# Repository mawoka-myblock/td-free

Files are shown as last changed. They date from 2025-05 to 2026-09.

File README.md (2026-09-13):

# Td-Free

A free and open source device to measure the td value of your filaments.

The CAD is available in the [onshape workspace](https://cad.onshape.com/documents/e7ec65aec40b24c9a33c1902/w/dc90f86d4d08d2181a707cee/e/a86c6c8c0a4124509901ffce)
(licensed under [CC BY-SA 4.0](https://creativecommons.org/licenses/by-sa/4.0/)) and the print files can be downloaded from [Printables](https://www.printables.com/model/919380-td-free)

## Comparison to TD-1 by Ajax

| TD-Free | TD-1 |
| --- | --- |
| **Small** | Slightly bigger |
| **Cheap** | More expensive |
| Measures td and color | **Measures color and td** |
| WiFi-enabled | Only via usb and screen |
| **Open-Source Code** | Closed source |
| **No license required** | License needs to be purchased |
| No integrations available | **Perfectly integrated into HueForge** |
| **CAD available** | CAD not available |
| only for checking samples | **monitor td of spool as it's printing** |

So, in summary, the Td-Free is **cheaper**, **open-source**, **smaller** and **wifi-enabled**.

## Buy one

**Explore [my online store](https://mawoka.eu/shop) where you can buy the PCB or a fully assembled Td-Free.**

## Make one

### Buy only the PCB

If you got the PCB, just print the parts provided at [Printables](https://www.printables.com/model/919380-td-free-an-open-source-alternative-to-the-td-1).
You have to use black filament for the specifc parts marked as such, but for the others, you can mix and match them! Let's get to the assembly:

1. Insert the LED module into the position in the case at the bottom. Press it down firmly.
2. Insert the two black pieces. The one with the channel first, so that the channel is open to the top. Make sure you see the yellow LED module through the hole in the channel!
3. Now, insert the second black piece with the rectangular cutout as well. Make sure again that the cutout is above the LED hole.
4. Slide the PCb with the USB-C connector in at an angle and make sure it's fully slid in.
5. Push the PCb into place and make sure it is really sitting flat. **Watch out for the LED cable to not get damaged!**
6. Put the lid on
7. Done! Measure your Td!

### From Scratch
Get the PCB from a manufacturer like JLCPCB, PCBway or whatever. Now, you'll also want to get the following components:
- `VEML7700` (TR or TT is only about the packaging, so choose the cheaper one)
- `WS2812B` (In the 5050 variant)
- `ESP32-C3 Supermini` ([Here from AliExpress](https://s.click.aliexpress.com/e/_DmNdnTB))
- `AOSS32334C`
- [This LED module](https://s.click.aliexpress.com/e/_DF3Gdpb) Get the Cold White version

Solder all your parts to the PCB. The LED module cables have to solderd from the bottom and should be around 45mm long.
Now, follow all the steps from above. For flashing, just follow the instructions to get Esp-rs working and run `cargo run --release`.

## Looking for the old README?
Click [here](https://github.com/mawoka-myblock/td-free/blob/v2.0.0/README.md).

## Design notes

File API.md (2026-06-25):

# API Docs

## REST

### GET / App HTML
Gets the main index.html

### GET /app.js App JS
Gets the main app.js

### GET /app.css App CSS
Gets the main app.css

### GET /events/data SSE for data
Gets the data measured by the device.

Event is `measurement_changed` and either contains:

```
no_filament
```

or

```json
{
    "td": "2.5",
    "hex_color": Option<"FFFFFF">,
    "buf_color": Option<12>
}
```

### GET/POST /config/settings Set/Get Config
Sets/Gets settings:

```json5
{
    "led_brightness": 100, // in %
    "algo": {
        "b": 0.0,
        "m": 1.0,
        "threshold": 0.9 // between 0.999 and 0.001
    }
}
```

### GET/POST /config/rgb Set/Get RGB Multipliers
Sets/Gets rgb multipliers:
```json
{
    "red": 1.0,
    "green": 1.0,
    "blue": 1.0,
    "brightness": 1.0,
    "td_reference": 50.0,
    "reference_r": 127,
    "reference_g": 127,
    "reference_b": 127
}
```

### POST /config/wifi Set Wifi Credentials
```json
{
    "ssid": "dsada",
    "password": "dsads"
}
```

### GET /config/info Get Device Info
```json
{
    "has_color": true,
    "version": "06556+4-3.3"
}
```

### POST /config/auto-calibrate Set Auto-calibrate data
Need client listening to server sent events (`/events/data`)

may throw 428 if no client connected

may throw 408 if internal function timeouted

```json
{
    "target_r": 255,
    "target_g": 255,
    "target_b": 255
}
```

Return RGBMultipliers like `/config/rgb`

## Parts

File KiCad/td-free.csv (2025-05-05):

Id | Designator | Footprint | Quantity | Designation | Supplier and ref
1 | U1 | ESP32-C3-WROOM-02 | 1 | ESP32-C3-WROOM-02
2 | J1 | PinHeader_1x02_P2.54mm_Vertical | 1 | Conn_01x02_Pin
3 | U4 | SMD_L3328_VIS | 1 | VEML3328
4 | J2 | USB_C_Receptacle_GCT_USB4105-xx-A_16P_TopMnt_Horizontal | 1 | USB_C_Receptacle_USB2.0_14P
5 | U5 | USON-10_2.5x1.0mm_P0.5mm | 1 | TPD4E05U06DQA
6 | U3 | SOT-223-3_TabPin2 | 1 | AMS1117-3.3
7 | U2 | XDCR_VEML7700-TR | 1 | VEML7700-TT
8 | R3 | R_0805_2012Metric_Pad1.20x1.40mm_HandSolder | 1 | 10kO
9 | R2,R1 | R_0805_2012Metric_Pad1.20x1.40mm_HandSolder | 2 | 5k1
10 | D2 | D_SMA | 1 | SMAJ5.0A
11 | C6,C4,C1 | C_0805_2012Metric_Pad1.18x1.45mm_HandSolder | 3 | 10uF
12 | C5 | C_0805_2012Metric_Pad1.18x1.45mm_HandSolder | 1 | 0.1uF
13 | C3,C2 | C_0805_2012Metric_Pad1.18x1.45mm_HandSolder | 2 | 22uF
14 | D1 | LED_WS2812B_PLCC4_5.0x5.0mm_P3.2mm | 1 | WS2812B
15 | Q1 | SOT-23 | 1 | 2N7002

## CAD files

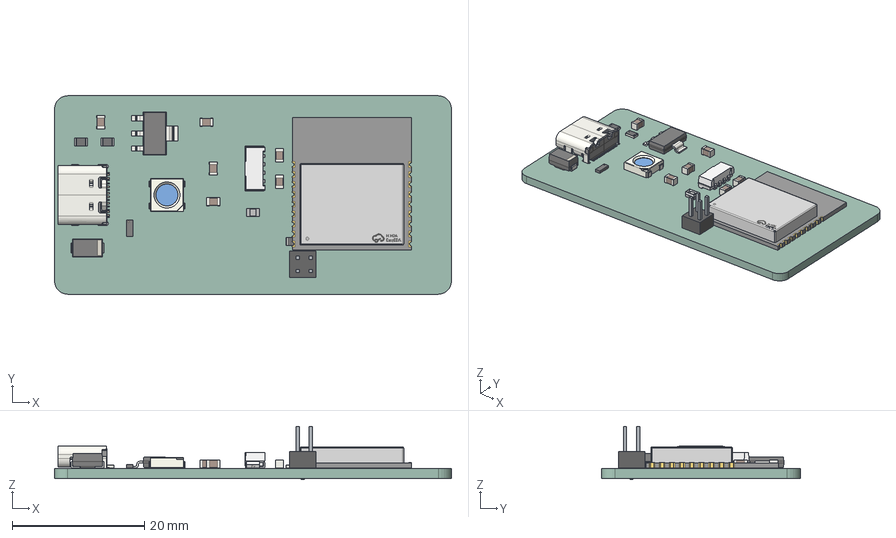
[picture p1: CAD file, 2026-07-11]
KiCad/boards/main.step
60.0 x 30.0 x 8.05 mm
USB_C_Receptacle_16P_TopMnt_Horizontal_GCT_USB4105-xx-A
BULETM-SMD_ESPRESSIF_ESP32-C3-WROOM-02-N4-4MB
R_0805_2012Metric x 3
LED-SMD_4P-L6.8-W2.4_VEML7700-TR
C_0805_2012Metric x 6
USON_10_25x10mm_Pitch05mm
SENSOR-SMD_VEML3328
LED_WS2812B_PLCC4_50x50mm_P32mm
SOT-223
2x2 Header
D_SMA
main_PCB

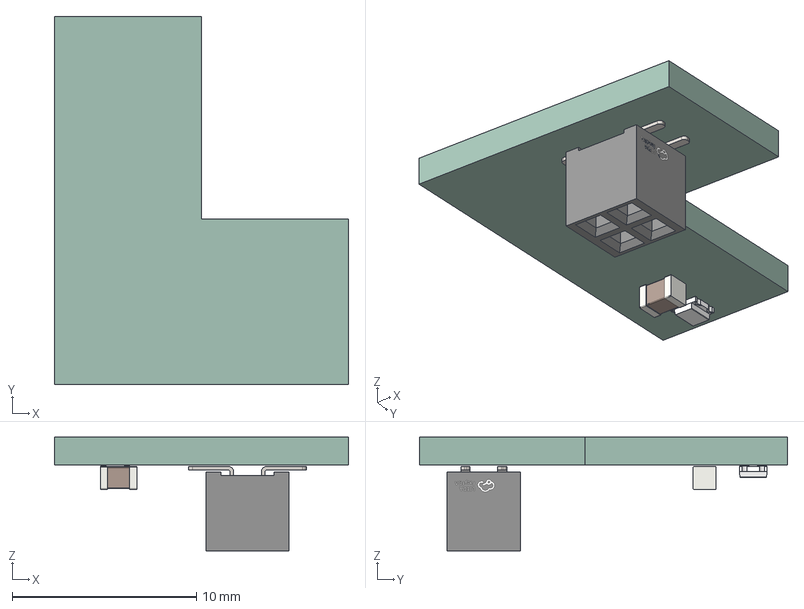
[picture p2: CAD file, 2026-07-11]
KiCad/boards/led.step
16.0 x 20.0 x 6.19 mm
LED-SMD_4P-L1.6-W1.5_XL-1615RGBC-WS2812B-1
C_0805_2012Metric
HDR-SMD_4P-P2.00-V-F-R2-C2-LS6.4
led_PCB

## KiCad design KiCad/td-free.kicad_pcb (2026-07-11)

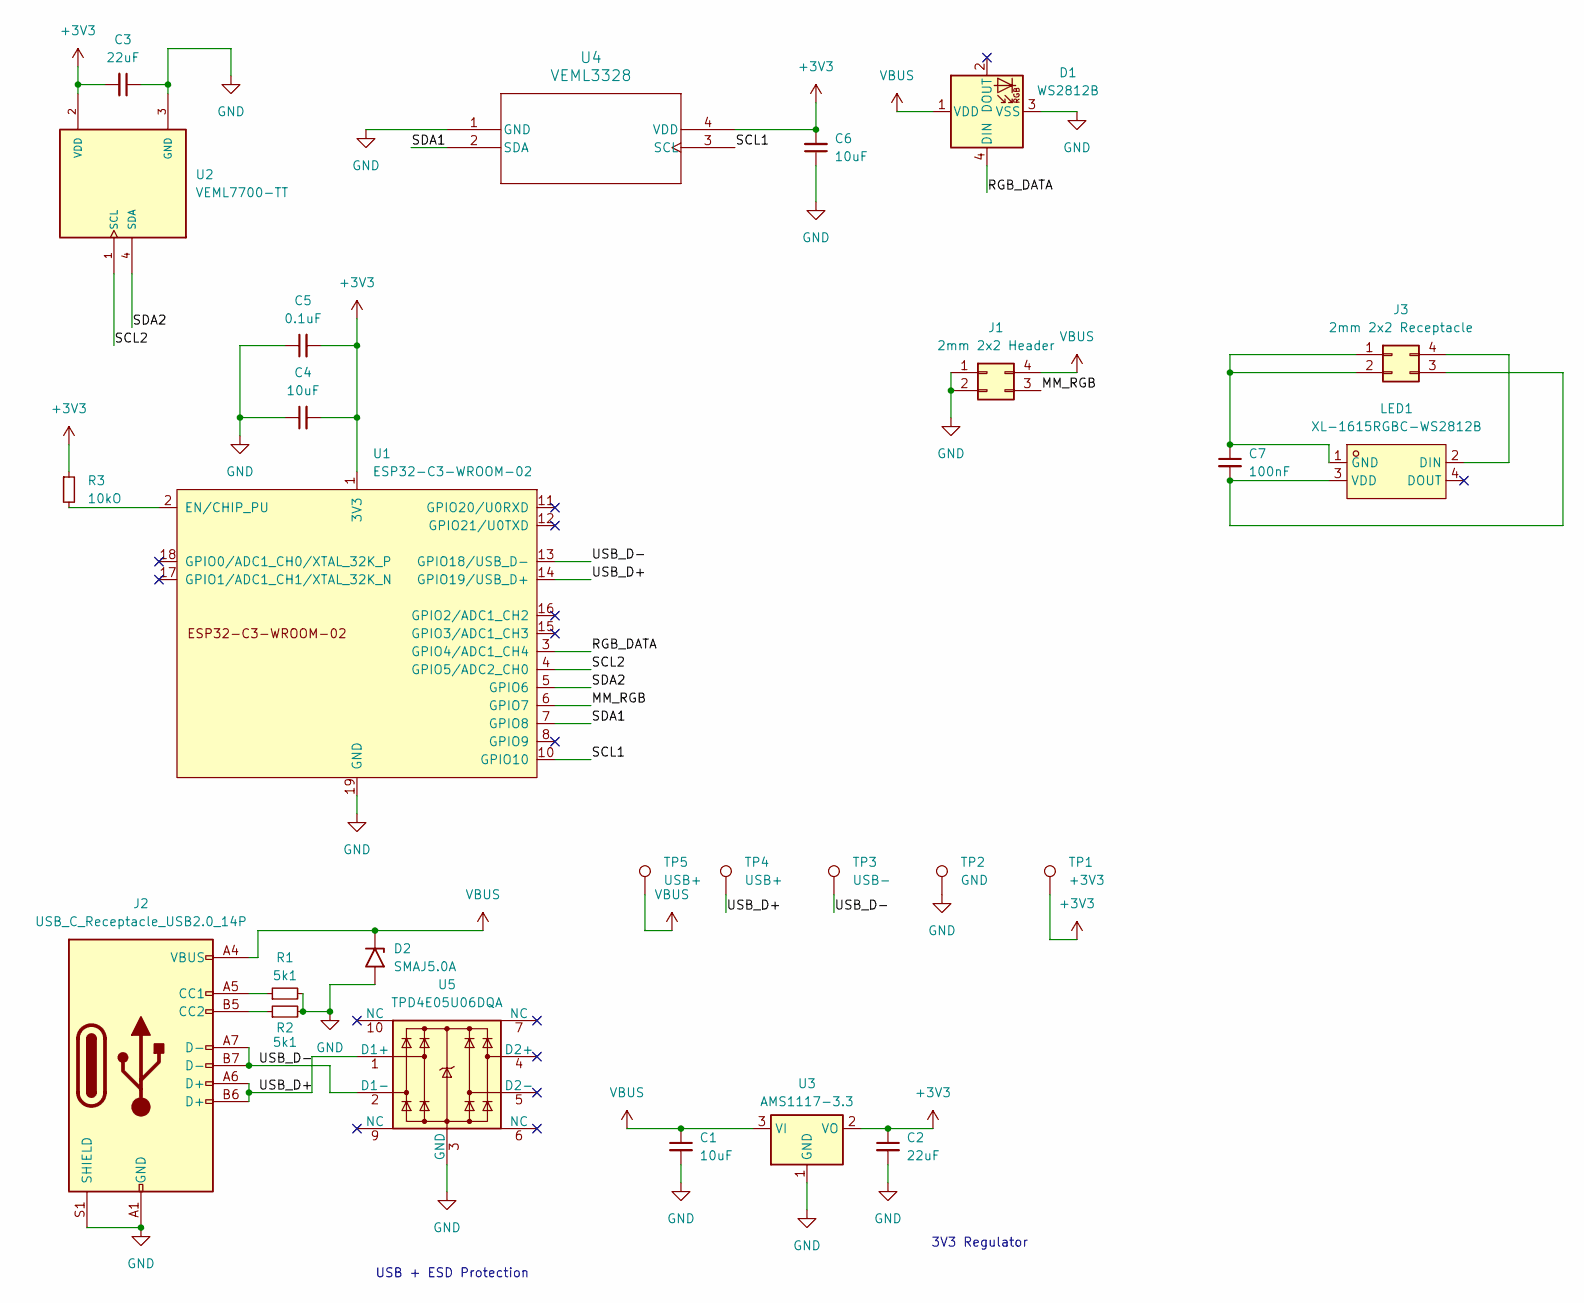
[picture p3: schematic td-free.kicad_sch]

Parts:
C1, C4, C6: 10uF; C_0805_2012Metric
C2, C3: 22uF; C_0805_2012Metric
C5: 0.1uF; C_0805_2012Metric
C7: 100nF; C_0805_2012Metric
D1: WS2812B; LED_WS2812B_PLCC4_5.0x5.0mm_P3.2mm
D2: SMAJ5.0A; D_SMA
J1: 2mm 2x2 Header; HDR-SMD_4P-P2.00-V-M-R2-C2-LS6.4-EH
J2: USB_C_Receptacle_USB2.0_14P; USB_C_Receptacle_GCT_USB4105-xx-A_16P_TopMnt_Horizontal
J3: 2mm 2x2 Receptacle; PinHeader_2x02_P2.00mm_Vertical_SMD
LED1: XL-1615RGBC-WS2812B; LED-SMD_4P-L1.6-W1.5_XL-1615RGBC-WS2812B-1; LCSC Part C5349954
R1, R2: 5k1; R_0805_2012Metric_Pad1.20x1.40mm_HandSolder
R3: 10kO; R_0805_2012Metric_Pad1.20x1.40mm_HandSolder
TP1: +3V3; TestPoint_Pad_D1.0mm
TP2: GND; TestPoint_Pad_D1.0mm
TP3: USB-; TestPoint_Pad_D1.0mm
TP4, TP5: USB+; TestPoint_Pad_D1.0mm
U1: ESP32-C3-WROOM-02
U2: VEML7700-TT; XDCR_VEML7700-TT; PARTREV 1.6
U3: AMS1117-3.3; SOT-223-3_TabPin2
U4: VEML3328; SMD_L3328_VIS
U5: TPD4E05U06DQA; USON-10_2.5x1.0mm_P0.5mm

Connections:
+3V3: C2.1, C3.2, C4.2, C5.2, C6.2, R3.1, TP1.1 (1_1), U1.1 (3V3), U2.2 (VDD), U3.2 (VO), U4.4 (VDD)
/MM_RGB: J1.3, U1.6 (GPIO7)
/RGB_DATA: D1.4 (DIN), U1.3 (GPIO4/ADC1_CH4)
/SCL1: U1.10 (GPIO10), U4.3 (SCL)
/SCL2: U1.4 (GPIO5/ADC2_CH0), U2.1 (SCL)
/SDA1: U1.7 (GPIO8), U4.2 (SDA)
/SDA2: U1.5 (GPIO6), U2.4 (SDA)
/USB_D+: J2.A6 (D+), J2.B6 (D+), TP4.1 (1_1), U1.14 (GPIO19/USB_D+), U5.1 (D1+)
/USB_D-: J2.A7 (D-), J2.B7 (D-), TP3.1 (1_1), U1.13 (GPIO18/USB_D-), U5.2 (D1-)
GND: C1.2, C2.2, C3.1, C4.1, C5.1, C6.1, D1.3 (VSS), D2.2 (A2), J1.1, J1.2, J2.A1 (GND), J2.A12 (GND), J2.B1 (GND), J2.B12 (GND), J2.S1 (SHIELD), R1.2, R2.2, TP2.1 (1_1), U1.9 (GND), U1.19 (GND), U2.3 (GND), U3.1 (GND), U4.1 (GND), U5.3 (GND), U5.8 (GND)
unnamed: J2.A5 (CC1), R1.1
unnamed: J2.B5 (CC2), R2.1
unnamed: C7.1, J3.1, J3.2, LED1.1 (GND)
unnamed: C7.2, J3.3, LED1.3 (VDD)
unnamed: J3.4, LED1.2 (DIN)
unnamed: R3.2, U1.2 (EN/CHIP_PU)
VBUS: C1.1, D1.1 (VDD), D2.1 (A1), J1.4, J2.A4 (VBUS), J2.A9 (VBUS), J2.B4 (VBUS), J2.B9 (VBUS), TP5.1 (1_1), U3.3 (VI)

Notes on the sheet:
3V3 Regulator
USB + ESD Protection

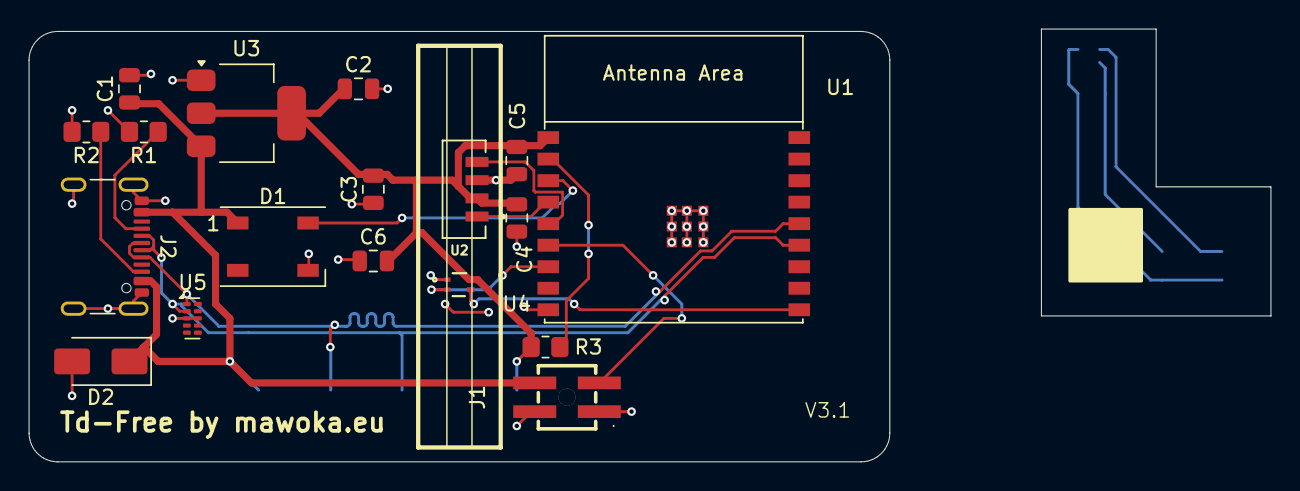
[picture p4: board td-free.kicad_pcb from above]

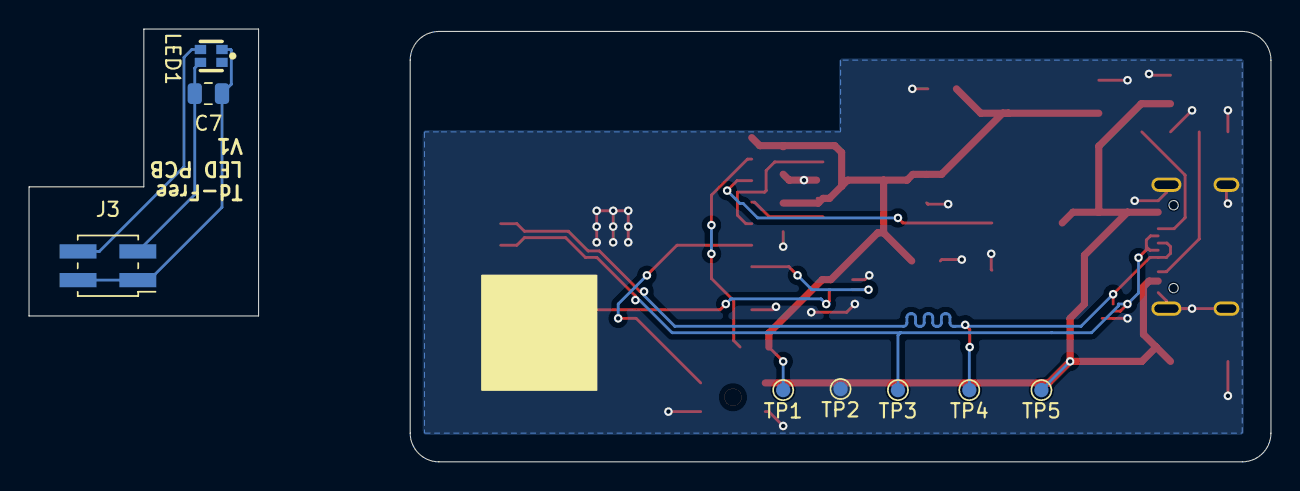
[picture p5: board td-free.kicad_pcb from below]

Board: 2 copper layers, 60.0 x 30.0 mm, 28 parts (8 on the bottom side), 17 nets.

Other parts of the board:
B1, B2: Board

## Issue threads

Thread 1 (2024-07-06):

No build available

Johannes-Sch, 2024-07-06:
Hi,
at the moment there is no build available and the link in the flashing instructions gives a 404 error.
Could you please upload a release?

Thanks and KR
Johannes

Johannes-Sch, 2024-07-06:
Thanks for the fast reply!

I used the image with this command to flash it:
.\esptool.exe -b 230400 write_flash 0x0 .\firmware.bin

But I get the following error:
Unexpected chip id in image. Expected 0 but value was 5. Is this image for a different chip model?
A fatal error occurred: .\firmware.bin is not an ESP32 image. Use --force to flash anyway.

I use the ESP32-C3 that is linked in the Shopping List.

If I use .\esptool.exe -b 230400 write_flash 0x0 .\firmware.bin --force to flash it anyway it does go through but when I power everything the red LED on the board stays on, the blue LED is blinking and there is no wifi hotspot (even after a few minutes there is no change to that).

Any idea what the problem is or how I can debug this?

mawoka-myblock, 2024-07-06:
Try erasing the chip (`esptool.exe erase_flash`) and maybe try again

mawoka-myblock, 2024-07-06:
I've missed mentioning a crucial step: Holding the `BOOT` button while plugging the esp in.

Johannes-Sch, 2024-07-06:
I tried erasing the chip and flashing it again (also with the --force argument). Before flashing, I was holding the boot button, which resulted in no blue LED flashing while flashing the image.

Sadly, there is no change in the behavior when plugin it into power. Is there a way to verify if the flashing was even successful, or is the blue LED flashing already an indication that it was not?

mawoka-myblock, 2024-07-06:
If you only erase the chip, does it then stop blinking blue? When the correct firmware is flashed, it should only blink periodically and not constantly that fast.

mawoka-myblock, 2024-07-06:
Nevermind, the chip shouldn't flash at all with the correct firmware when none of the other components are attached.

Johannes-Sch, 2024-07-06:
Okay, I made an interesting discovery. On my main PC, I always had to use the --force argument. I now tried flashing the firmware with my laptop (also with a different cable USB-C to USB-C instead of USB-A to USB-C but not sure if that makes a difference)

mawoka-myblock, 2024-07-06:
It *shouldn't* make a difference

Johannes-Sch, 2024-07-06:
I tried reading the serial output with the serial monitor in the Arduino IDE. After flashing, I get this message (it repeats this):

load:0x4038c1bc,len:0x14cc
ESP-ROM:esp32c3-api1-20210207
Build:Feb  7 2021
rst:0x7 (TG0WDT_SYS_RST),boot:0xf (SPI_FAST_FLASH_BOOT)
Saved PC:0x40380080
SPIWP:0xee
mode:DIO, clock div:1
load:0x3c0a0020,len:0x20390
load:0x3fc8d800,len:0x3a9c
load:0x40380000,len:0xc1bc
load:0x42000020,len:0x95920
load:0x4038c1bc,len:0x14cc
SHA-256 comparison failed:
Calculated: cebc1b341a418d75d08e64a66da52bdc3515c5817809a3983f2c00b1bb60a996
Expected: 0101a90055996720ee2eec6ad3d34a4aa37930cc65991d86f5ce4ffbd98c362c
Attempting to boot anyway...
entry 0x40381d74

mawoka-myblock, 2024-07-06:
Did you buy a second esp32c3? It seems like the storage (flash) on it may be broken. I'll remove this specifc vendor from the list.

Johannes-Sch, 2024-07-06:
I just ordered two new ones from a different vendor. One good thing with AliExpress: already got my money back.
I will try again in about a week when the new ones are delivered.

Johannes-Sch, 2024-07-16:
Alright, today two new esp's got delivered.
I tried flashing it again with .\esptool.exe -b 230400 write_flash 0x0 .\firmware.bin however again got the same error as last time;

Next, I downloaded the entire project from git and uploaded a newly compiled firmware directly from VSCode. This was indeed successful! The Td-Free hotspot can be seen and connected to.

Don't know if that's the problem, but in the VS project the upload_speed is set to 460800 and in the flash command the rate is set to 230400. (Probably not, just tried flashing with just the different rate and got the same error again).

Another thing I noticed is that VSC flashes to 0x0001:
Wrote 814784 bytes (486112 compressed) at 0x00010000

And the command to 0x0:
Wrote 814656 bytes (486070 compressed) at 0x00000000

But there is still another problem (probably because I flashed with VSC). I can connect to the hotspot, but the website can not be loaded (http://192.168.0.1). The browser just load forever and don't display anything. I also did not solder anything yet, it's just the ESP, but that should not cause this or could it?

mawoka-myblock, 2024-07-16:
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

Okay. That's strange, it probably has something to do with the bootloader being missing, so I'll have to investigate in 2 weeks when I'll be back home, but I'll put up a note in the readme.

To your second point: This indeed happens, as the esp is waiting indefinitely for data from the sensor. So you "just" have to solder the rest together. Out of curiosity: Have you chosen the 24v or the 12v components?

Johannes-Sch, 2024-07-16:
Thanks!

I will put everything back together later this week and hopefully it works ^^.

I'm using the 12v components.

mawoka-myblock, 2024-07-16:
Okay, now you should be able to flash the file directly, just like it's written in the instructions.

Johannes-Sch, 2024-07-16:
At least we got a different error. The message repeats, then the esp resets and the messages get displayed again.

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

mawoka-myblock, 2024-07-25:
How's the build going?

Johannes-Sch, 2024-07-30:
I'm still facing the same issue that the website loads forever. I noticed that the VEML7700 gets quite hot after a short period of time. Maybe I fried it somehow.
It also could still be a flashing error, since I could not use your last file (see my last post) and used the upload function from Visual Studio.

mawoka-myblock, 2024-07-31:
Have you set the step-down converter to 5v? This was missing in the instructions. If not, this may have fried your sensor and/or the esp32. Huge apologies for forgetting to mention that! That was the most important step I forgot! I've now added it into the README

Johannes-Sch, 2024-08-01:
Oh man, that's something I could have thought of myself... It was set to 11,V I'm surprised the ESP survived so far. Well I already had ordered a new sensor which will be here next week.

Johannes-Sch, 2024-08-07:
Yeah, it works ^^!
I can not close the case at the moment because of the plugs/cables I used, but it works!
Got also quite good measurements, the Bambu PLA Basic Orange is standard 5,6 in HueForge and I measured between 5,57 and ~6.

Thanks for all your help over the weeks, I really appreciate it!

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

mawoka-myblock, 2024-08-07:
Man, that's so cool! Also knowing that the td-free is quite accurate as I had no way to verify the TD myself, so I only used the step tests

mawoka-myblock, 2024-08-09:
The problem with the prebuilt binary should be fixed now! 🥳  Thanks again for being the first tester and getting the instructions clear(er)

Closed 2024-08-07.

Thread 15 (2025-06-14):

settings can't be saved

LE1ED4523, 2025-06-14:
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
in Further Settings after click save esp32 reboot but nothing changed

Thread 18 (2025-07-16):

TD-Free not working at all

seancamos247-dotcom, 2025-07-16:
I flashed the new firmware and screen said it was successful.
Now I can no longer connect to the device at all.
I then downgraded to old firmware and still the same problem.
I must be doing something wrong.
Before the upgrade was working fine.
When i plug in USB lead my PC beeps as if recognising a device connection but I cannot access the device through the i.p. in Chrome.

mawoka-myblock, 2025-07-16:
Which OS do you use?

seancamos247-dotcom, 2025-07-16:
When I connect device LED starts green then immediately goes white

mawoka-myblock, 2025-07-16:
Please follow the instructions from https://github.com/mawoka-myblock/td-free/issues/17#issuecomment-3071130360 to provide the logs, as the white LED indicates a crash

seancamos247-dotcom, 2025-07-16:
Welcome to the Advanced Browser-based Cereal Terminal.

 $  ESP-ROM:esp32c3-api1-20210207
I (7049) td_free_rs::helpers::baseline_readings: RGB white balance raw medians: R=27813, G=38465, B=38517, Clear=38632
[0;32mI (7049) td_free_rs::helpers::baseline_readings: Spectral response ratios (relative to Green): R=0.723, B=1.001
[0;32mI (7059) td_free_rs::helpers::baseline_readings: Color temperature corrected: R=27813, G=38465, B=38517
I (7569) td_free_rs::helpers::baseline_readings: Reading: 471.8592
I (7669) td_free_rs::helpers::baseline_readings: Reading: 508.0896
[0;32mI (7769) td_free_rs::helpers::baseline_readings: Reading: 472.03198
[0;32mI (7869) td_free_rs::helpers::baseline_readings: Reading: 471.8592
[0;32mI (7969) td_free_rs::helpers::baseline_readings: Reading: 471.8592
[0;32mI (8069) td_free_rs::helpers::baseline_readings: Reading: 508.03198
I (8169) td_free_rs::helpers::baseline_readings: Reading: 471.8016
I (8269) td_free_rs::helpers::baseline_readings: Reading: 471.8592
I (8369) td_free_rs::helpers::baseline_readings: Reading: 507.9744
[0;32mI (8469) td_free_rs::helpers::baseline_readings: Reading: 471.8592
I (8569) td_free_rs::helpers::baseline_readings: Reading: 471.8592
0;32mI (8669) td_free_rs::helpers::baseline_readings: Reading: 471.91678
I (8769) td_free_rs::helpers::baseline_readings: Reading: 505.728
[0;32mI (8869) td_free_rs::helpers::baseline_readings: Reading: 472.896
I (8969) td_free_rs::helpers::baseline_readings: Reading: 471.91678
I (9069) td_free_rs::helpers::baseline_readings: Reading: 494.1504
[0;32mI (9169) td_free_rs::helpers::baseline_readings: Reading: 494.1504
I (9269) td_free_rs::helpers::baseline_readings: Reading: 485.0496
I (9369) td_free_rs::helpers::baseline_readings: Reading: 470.99518
I (9469) td_free_rs::helpers::baseline_readings: Reading: 483.0336
I (9569) td_free_rs::helpers::baseline_readings: Baseline calculation: mean=482.45, std=14.36, median=471.97
I (9569) td_free_rs: Baseline readings completed with white balance calibration
[0;32mI (9579) esp_idf_svc::nvs: EspNvs dropped
[0;32mI (9579) esp_idf_svc::nvs: EspNvs dropped
[0;32mI (9579) td_free_rs: Server created
I (14589) td_free_rs: Running HTTP server on 0.0.0.0:80
I (14589) td_free_rs: Loaded RGB multipliers: R=1.00, G=1.00, B=1.00, Brightness=1.00, TD_ref=50.00
I (14589) async_io_mini::reactor: Starting reactor
[0;32mI (14599) edge_http::io::server: Creating 2 handler tasks, memory: 2760B
________________________________
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

mawoka-myblock, 2025-07-16:
Everything looks normal. Pleas try to power it from a wall adapter instead of your PC and see if then can access the web UI

seancamos247-dotcom, 2025-07-16:
Same result from wall adapter.
How do i set up from scratch?
What ip should the browser be looking for?

seancamos247-dotcom, 2025-07-16:
Had to reset the WiFi details.
Now loads to V 8 and "seems" to work.
Is there a guide to calibration?
Many colours seem to be showing as white.

mawoka-myblock, 2025-07-23:
To calibrate the color sensor click on the "Calibrate" link in the footer, and insert your filament. Now, select the color of your filament in the color chooser. After that, click on "Auto Calibrate" and that's it. It is supposed to work best with a grey(ish) filament.

Closed 2025-07-23.

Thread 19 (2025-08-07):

cannot get to flash screen for ver 0.8

Adiel-Sharabi, 2025-08-07:
After connecting to the pc, I can see the update screen - click connect got the popup with the com5 device  (the only option)
Click on connect and the text gone but connecting stay grayed out.
Any ideas?
Also tried different browsers (Chrome, Edge) - In-private windows, clean cache.
Browder consol is like that:

```
update:7   GET https://plausible.nexus.mawoka.eu/js/script.file-downloads.outbound-links.pageview-props.revenue.tagged-events.js net::ERR_BLOCKED_BY_CLIENT
25.Bn01iXlg.js:30 ESPLoader: class qr{constructor(i){this.ESP_RAM_BLOCK=6144,this.ESP_FLASH_BEGIN=2,this.ESP_FLASH_DATA=3,this.ESP_FLASH_END=4,this.ESP_MEM_BEGIN=5,this.ESP_MEM_END=6,this.ESP_MEM_DATA=7,this.ESP_WRITE_REG=9,this.ESP_R…
25.Bn01iXlg.js:30 Transport: class Pr{constructor(i,e=!1,a=!0){this.device=i,this.tracing=e,this.slipReaderEnabled=!1,this.leftOver=new Uint8Array(0),this.baudrate=0,this.traceLog="",this.lastTraceTime=Date.now(),this._DTR_state=!1,th…
update:1 Chooser dialog is not displaying a port blocked by the Serial blocklist: bluetoothServiceClassId=0000110b-0000-1000-8000-00805f9b34fb, name='Bose QC35 II'
update:1 Chooser dialog is not displaying a port blocked by the Serial blocklist: bluetoothServiceClassId=0000110c-0000-1000-8000-00805f9b34fb, name='Bose QC35 II'
update:1 Chooser dialog is not displaying a port blocked by the Serial blocklist: bluetoothServiceClassId=0000110e-0000-1000-8000-00805f9b34fb, name='Bose QC35 II'
update:1 Chooser dialog is not displaying a port blocked by the Serial blocklist: bluetoothServiceClassId=00001108-0000-1000-8000-00805f9b34fb, name='Bose QC35 II'
update:1 Chooser dialog is not displaying a port blocked by the Serial blocklist: bluetoothServiceClassId=0000111e-0000-1000-8000-00805f9b34fb, name='Bose QC35 II'
update:1 Chooser dialog is not displaying a port blocked by the Serial blocklist: bluetoothServiceClassId=00001124-0000-1000-8000-00805f9b34fb, name='WH-1000XM5'
update:1 Chooser dialog is not displaying a port blocked by the Serial blocklist: bluetoothServiceClassId=0000110e-0000-1000-8000-00805f9b34fb, name='WH-1000XM5'
update:1 Chooser dialog is not displaying a port blocked by the Serial blocklist: bluetoothServiceClassId=00001108-0000-1000-8000-00805f9b34fb, name='WH-1000XM5'
update:1 Chooser dialog is not displaying a port blocked by the Serial blocklist: bluetoothServiceClassId=0000110c-0000-1000-8000-00805f9b34fb, name='WH-1000XM5'
update:1 Chooser dialog is not displaying a port blocked by the Serial blocklist: bluetoothServiceClassId=0000110b-0000-1000-8000-00805f9b34fb, name='WH-1000XM5'
update:1 Chooser dialog is not displaying a port blocked by the Serial blocklist: bluetoothServiceClassId=0000111e-0000-1000-8000-00805f9b34fb, name='WH-1000XM5'
index.D_iNqvlf.js:4 esptool.js
index.D_iNqvlf.js:4 Serial port WebSerial VendorID 0x303a ProductID 0x1001
index.D_iNqvlf.js:4 Connecting...
index.D_iNqvlf.js:4 Debug: _connect_attempt default_reset false
index.D_iNqvlf.js:4 Debug: Timeout
index.D_iNqvlf.js:4 Debug: Sync
index.D_iNqvlf.js:4 Debug: Sync err Error: Timeout
index.D_iNqvlf.js:4 .
index.D_iNqvlf.js:4 Debug: Sync
index.D_iNqvlf.js:4 Debug: 538052359
index.D_iNqvlf.js:4

index.D_iNqvlf.js:4 Debug: Chip Magic 1b31506f
index.D_iNqvlf.js:4 Detecting chip type...
index.D_iNqvlf.js:4 ESP32-C3
index.D_iNqvlf.js:4 Chip is ESP32-C3 (revision 4)
index.D_iNqvlf.js:4 Features: Wi-Fi,BLE
index.D_iNqvlf.js:4 Crystal is 40MHz
index.D_iNqvlf.js:4 MAC: 34:cd:b0:89:9b:f8
index.D_iNqvlf.js:4 Uploading stub...
index.D_iNqvlf.js:4 Debug: mem_begin 3748 1 6144 40380000
index.D_iNqvlf.js:4 Debug: check_command enter RAM download mode
index.D_iNqvlf.js:4 Debug: check_command write to target RAM
index.D_iNqvlf.js:4 Debug: mem_begin 160 1 6144 3fc96bb0
index.D_iNqvlf.js:4 Debug: check_command enter RAM download mode
index.D_iNqvlf.js:4 Debug: check_command write to target RAM
index.D_iNqvlf.js:4 Running stub...
index.D_iNqvlf.js:4 Debug: check_command leave RAM download mode
index.D_iNqvlf.js:4 Stub running...
index.D_iNqvlf.js:4 Changing baudrate to 230400
index.D_iNqvlf.js:4 Debug: 0
index.D_iNqvlf.js:4 Changed
index.D_iNqvlf.js:4 Debug: Sync
index.D_iNqvlf.js:4 Debug: flash_id
index.D_iNqvlf.js:4 Debug: check_command write target memory
index.D_iNqvlf.js:4 Debug: check_command write target memory
index.D_iNqvlf.js:4 Debug: check_command write target memory
index.D_iNqvlf.js:4 Debug: check_command write target memory
index.D_iNqvlf.js:4 Debug: check_command write target memory
index.D_iNqvlf.js:4 Debug: check_command write target memory
index.D_iNqvlf.js:4 Debug: check_command write target memory
index.D_iNqvlf.js:4 Manufacturer: 20
index.D_iNqvlf.js:4 Device: 4016
index.D_iNqvlf.js:4 Detected flash size: 4MB
25.Bn01iXlg.js:5  Uncaught (in promise) TypeError: Cannot read properties of undefined (reading 'branch')
    at ue (25.Bn01iXlg.js:5:70)
    at Object.p (25.Bn01iXlg.js:30:3781)
    at st (scheduler.BvJ8Bb52.js:1:8208)
    at ct (scheduler.BvJ8Bb52.js:1:7861)
ue @ 25.Bn01iXlg.js:5
p @ 25.Bn01iXlg.js:30
st @ scheduler.BvJ8Bb52.js:1
ct @ scheduler.BvJ8Bb52.js:1
Promise.then
nt @ scheduler.BvJ8Bb52.js:1
ht @ index.B9s6ybwJ.js:4
(anonymous) @ index.B9s6ybwJ.js:4
Te._ @ 25.Bn01iXlg.js:30
await in Te._
(anonymous) @ scheduler.BvJ8Bb52.js:1
Kt @ scheduler.BvJ8Bb52.js:1
T @ BrownButton.DBqGxcXU.js:1
```

mawoka-myblock, 2025-08-10:
Is fixed, was an issue on my end. Please try again.

Closed 2025-08-10.

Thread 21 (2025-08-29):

not able to get color measurement working

frankyifei, 2025-08-29:
there is no such option in my webui, what could go wrong? I am on version 0.82, firefox working well, not able to open webui on chrome. I made my own board, it is v2.1

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

Closed 2025-08-30.

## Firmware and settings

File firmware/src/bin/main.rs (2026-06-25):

#![no_std]
#![recursion_limit = "512"]
#![no_main]
#![deny(
    clippy::mem_forget,
    reason = "mem::forget is generally not safe to do with esp_hal types, especially those \
    holding buffers for the duration of a data transfer."
)]
#![deny(clippy::large_stack_frames)]
use defmt::info;
use defmt::warn;
use embassy_executor::Spawner;
use embassy_futures::select::Either;
use embassy_futures::select::select;
use embassy_net::Ipv4Cidr;
use embassy_net::StaticConfigV4;
use embassy_sync::mutex::Mutex;
use embassy_time::{Duration, Timer};
use esp_backtrace as _;
use esp_hal::clock::CpuClock;
use esp_hal::system::software_reset;
use esp_hal::timer::timg::TimerGroup;
use esp_hal::usb_serial_jtag::UsbSerialJtag;
use esp_println as _;
use esp_radio::wifi::ControllerConfig;
use esp_radio::wifi::ap::AccessPointConfig;
use esp_radio::wifi::sta::StationConfig;
use firmware::CLIENT_CONNECTED;
use firmware::helpers::storage::NvsStored as _;
use firmware::helpers::storage::WifiCreds;
use firmware::helpers::storage::nvs::Nvs;
use firmware::{NvsMutex, tasks};
use picoserve::AppBuilder;
extern crate alloc;

// This creates a default app-descriptor required by the esp-idf bootloader.
// For more information see: <https://docs.espressif.com/projects/esp-idf/en/stable/esp32/api-reference/system/app_image_format.html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>
esp_bootloader_esp_idf::esp_app_desc!();

#[allow(
    clippy::large_stack_frames,
    reason = "it's not unusual to allocate larger buffers etc. in main"
)]
#[esp_rtos::main]
async fn main(spawner: Spawner) -> ! {
    // generator version: 1.3.0
    // generator parameters: --chip esp32c3 -o esp32c3-wroom-02 -o unstable-hal -o alloc -o wifi -o embassy -o ble-trouble -o esp-backtrace -o defmt -o zed -o nightly-x86_64-unknown-linux-gnu

    let config = esp_hal::Config::default().with_cpu_clock(CpuClock::max());
    let peripherals = esp_hal::init(config);

    // The following pins are used to bootstrap the chip. They are available
    // for use, but check the datasheet of the module for more information on them.
    // - GPIO2
    // - GPIO8
    // - GPIO9
    // These GPIO pins are in use by some feature of the module and should not be used.
    let _ = peripherals.GPIO11;
    let _ = peripherals.GPIO12;
    let _ = peripherals.GPIO13;
    let _ = peripherals.GPIO14;
    let _ = peripherals.GPIO15;
    let _ = peripherals.GPIO16;
    let _ = peripherals.GPIO17;

    esp_alloc::heap_allocator!(#[esp_hal::ram(reclaimed)] size: 66320);
    // COEX needs more RAM - so we've added some more
    esp_alloc::heap_allocator!(size: 64 * 1024);

    let timg0 = TimerGroup::new(peripherals.TIMG0);
    let sw_interrupt =
        esp_hal::interrupt::software::SoftwareInterruptControl::new(peripherals.SW_INTERRUPT);
    esp_rtos::start(timg0.timer0, sw_interrupt.software_interrupt0);

    info!("Embassy initialized!");

    // find more examples https://github.com/embassy-rs/trouble/tree/main/examples/esp32
    // let transport = BleConnector::new(peripherals.BT, Default::default()).unwrap();
    // let ble_controller = ExternalController::<_, 1>::new(transport);
    // let mut resources: HostResources<DefaultPacketPool, CONNECTIONS_MAX, L2CAP_CHANNELS_MAX> =
    //     HostResources::new();
    // let _stack = trouble_host::new(ble_controller, &mut resources);
    CLIENT_CONNECTED.sender().send(false);

    let nvs: &'static NvsMutex = firmware::mk_static!(
        NvsMutex,
        Mutex::new(Nvs::new(firmware::NVS_OFFSET, firmware::NVS_SIZE, peripherals.FLASH).unwrap())
    );

    let wifi_creds = tasks::states::init_signals_and_get_wifi_creds(nvs).await;

    spawner.spawn(tasks::states::data_update_save_task(nvs).unwrap());
    spawner.spawn(tasks::leds::main_led_task(peripherals.LEDC, peripherals.GPIO7).unwrap());
    spawner.spawn(tasks::leds::rgb_led_task(peripherals.RMT, peripherals.GPIO4).unwrap());

    spawner.spawn(
        tasks::sensors::sensor_task(
            peripherals.GPIO6,
            peripherals.GPIO5,
            peripherals.GPIO8,
            peripherals.GPIO10,
            peripherals.I2C0,
        )
        .unwrap(),
    );

    let (rx, tx) = UsbSerialJtag::new(peripherals.USB_DEVICE)
        .into_async()
        .split();
    spawner.spawn(tasks::serial::handle_serial_task(tx, rx).unwrap());

    let (iface, net_config, wifi_controller) = if let Some(wf_creds) = wifi_creds.clone() {
        info!("Found wifi creds, trying to connect");
        firmware::WIFI_STATE
            .sender()
            .send(firmware::WifiState::Connecting);
        let sta_config = esp_radio::wifi::Config::Station(
            StationConfig::default()
                .with_ssid(wf_creds.ssid.as_str())
                .with_password(wf_creds.password.as_str().into()),
        );
        let (mut wifi_controller, interfaces) = esp_radio::wifi::new(
            peripherals.WIFI,
            ControllerConfig::default().with_initial_config(sta_config),
        )
        .expect("Failed to initialize Wi-Fi controller");

        let connect_is_err = wifi_controller.connect_async().await.is_err();
        if connect_is_err {
            warn!("Resetting wifi creds");
            let _ = WifiCreds::delete(nvs).await;
            Timer::after_millis(200).await;
            software_reset();
        }

        let mut dhcp_cfg = embassy_net::DhcpConfig::default();

        let mut hostname = heapless::String::new();
        hostname.push_str("td-free").unwrap();
        dhcp_cfg.hostname = Some(hostname);
        (
            interfaces.station,
            embassy_net::Config::dhcpv4(dhcp_cfg),
            wifi_controller,
        )
    } else {
        let ap_config = esp_radio::wifi::Config::AccessPoint(
            AccessPointConfig::default()
                .with_ssid("Td-Free")
                .with_auth_method(esp_radio::wifi::AuthenticationMethod::None),
        );
        let (wifi_controller, interfaces) = esp_radio::wifi::new(
            peripherals.WIFI,
            ControllerConfig::default().with_initial_config(ap_config),
        )
        .expect("Failed to initialize Wi-Fi controller");
        let ipv4_cfg = StaticConfigV4 {
            address: Ipv4Cidr::new(embassy_net::Ipv4Address::new(10, 10, 10, 1), 24),
            dns_servers: Default::default(),
            gateway: Some(embassy_net::Ipv4Address::new(10, 10, 10, 1)),
        };
        firmware::WIFI_STATE
            .sender()
            .send(firmware::WifiState::HotSpotRunning);
        (
            interfaces.access_point,
            embassy_net::Config::ipv4_static(ipv4_cfg),
            wifi_controller,
        )
    };
    let (stack, runner) = embassy_net::new(
        iface,
        net_config,
        firmware::mk_static!(
            embassy_net::StackResources<7>,
            embassy_net::StackResources::<7>::new()
        ),
        make_seed(),
    );
    spawner.spawn(tasks::http::network::net_task(runner).unwrap());

    if wifi_creds.is_some() {
        let has_ip_fut = async {
            info!("Checking for ip addr");
            loop {
                if let Some(config) = stack.config_v4() {
                    info!("Got IP: {}", config.address);
                    return config.address;
                }
                Timer::after_millis(200).await;
            }
        };
        let timeout_fut = Timer::after_secs(600);
        match select(has_ip_fut, timeout_fut).await {
            Either::First(_) => (),
            Either::Second(_) => {
                warn!("Resetting wifi creds");
                let _ = WifiCreds::delete(nvs).await;
                Timer::after_millis(200).await;
                software_reset()
            }
        }
        firmware::WIFI_STATE
            .sender()
            .send(firmware::WifiState::Connected);
    } else {
        spawner.spawn(
            tasks::http::network::listen_for_connect_event_wifi_ap(wifi_controller).unwrap(),
        );
        spawner.spawn(tasks::http::network::run_dhcp_server(stack).unwrap());
        spawner.spawn(tasks::http::network::captive_dns(stack).unwrap());
    }

    let app = firmware::mk_static!(
        picoserve::AppRouter<tasks::http::AppProps>,
        tasks::http::AppProps::new().build_app()
    );

    for task_id in 0..tasks::http::WEB_TASK_POOL_SIZE {
        spawner.spawn(tasks::http::web_task(task_id, stack, app).unwrap());
    }

    loop {
        Timer::after(Duration::from_secs(1)).await;
    }
}

fn make_seed() -> u64 {
    let rng = esp_hal::rng::Rng::new();
    ((rng.random() as u64) << 32) | rng.random() as u64
}

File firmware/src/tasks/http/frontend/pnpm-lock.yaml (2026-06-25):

lockfileVersion: '9.0'

settings:
  autoInstallPeers: true
  excludeLinksFromLockfile: false

importers:

  .:
    dependencies:
      preact:
        specifier: ^10.26.9
        version: 10.29.2
      preact-iso:
        specifier: ^2.12.0
        version: 2.12.0(preact-render-to-string@6.7.0(preact@10.29.2))(preact@10.29.2)
      preact-render-to-string:
        specifier: ^6.7.0
        version: 6.7.0(preact@10.29.2)
    devDependencies:
      '@preact/preset-vite':
        specifier: ^2.10.2
        version: 2.10.5(@babel/core@7.29.7)(preact@10.29.2)(rollup@4.61.1)(vite@7.3.5(jiti@2.7.0))
      eslint:
        specifier: ^10.4.1
        version: 10.4.1(jiti@2.7.0)
      eslint-config-preact:
        specifier: ^2.0.0
        version: 2.0.0(eslint@10.4.1(jiti@2.7.0))
      typescript:
        specifier: ^6.0.3
        version: 6.0.3
      unocss:
        specifier: ^66.7.0
        version: 66.7.0(vite@7.3.5(jiti@2.7.0))
      vite:
        specifier: ^7.0.4
        version: 7.3.5(jiti@2.7.0)
      vite-plugin-compression2:
        specifier: ^2.5.3
        version: 2.5.3(rollup@4.61.1)

packages:

  '@antfu/install-pkg@1.1.0':
    resolution: {integrity: sha512-MGQsmw10ZyI+EJo45CdSER4zEb+p31LpDAFp2Z3gkSd1yqVZGi0Ebx++YTEMonJy4oChEMLsxZ64j8FH6sSqtQ==}

  '@babel/code-frame@7.29.7':
    resolution: {integrity: sha512-Aup7aUOfpbAUg2ROOJN6Iw5f9DMBlzu0mIkm/malLQFN/YQgO48wCj0Kxa3sEHJvPVFg7siR+qRInwXd2qhQKw==}
    engines: {node: '>=6.9.0'}

  '@babel/compat-data@7.29.7':
    resolution: {integrity: sha512-locTkQyKvwIEgBzVrn8693ebc97F2U8ZHjbXwDXJ5Fn2TCpNwTlKcaKLkdHop5c/icOFE7qt7Q9JC5hnKNa6Gg==}
    engines: {node: '>=6.9.0'}

  '@babel/core@7.29.7':
    resolution: {integrity: sha512-RgHBCvtjbOK2gXSNBNIkNoEc9qoVEtau3hj8gEqKQuL3HZAibKarWFEI3Lfm6EYKkLalOh8eSrj9b+ch9H/VBA==}
    engines: {node: '>=6.9.0'}

  '@babel/eslint-parser@7.29.7':
    resolution: {integrity: sha512-zxt+UJTOMKvUt3yOg+D58MLuz334pHp93qifMFcjIIO+9hN6t+ufw2gi7vDPMpxvfnHRR+3VVXvIjineCcgyXw==}
    engines: {node: ^10.13.0 || ^12.13.0 || >=14.0.0}
    peerDependencies:
      '@babel/core': ^7.11.0
      eslint: ^7.5.0 || ^8.0.0 || ^9.0.0

  '@babel/generator@7.29.7':
    resolution: {integrity: sha512-DkXD5OJQaAQIdZ1bt3UZdEnHAn9Imd3IVBdX03UFe+ony9Ojw5pzr9YVKGDY1jt+Gcn/FnGkNf8r+Vj5NOJWtQ==}
    engines: {node: '>=6.9.0'}

  '@babel/helper-annotate-as-pure@7.29.7':
    resolution: {integrity: sha512-OoK6239jHPuSQOoS0kfTVKn0b/rVTk0seKq4Gd2UMLtmOVLjDC0ki3e+c90Trqv2gMfvJFqkiljrr568+qddiw==}
    engines: {node: '>=6.9.0'}

  '@babel/helper-compilation-targets@7.29.7':
    resolution: {integrity: sha512-wem6WaBj4NaVYVdNhLPPVacES6ZJ+KBBfSkTMD3YZxbP3rm3Di85tJU5ljaUNhaOynt+Aj0xruhYuzQBt8n71g==}
    engines: {node: '>=6.9.0'}

  '@babel/helper-globals@7.29.7':
    resolution: {integrity: sha512-3nQVUAtvkKH9zahfWgw96Jc/uFOmjACE1kQz82E2lqWmHBgjzbNlsC22nuQTfahmWeQtTq5nQ/4Nnd2A1wj4zA==}
    engines: {node: '>=6.9.0'}

  '@babel/helper-module-imports@7.29.7':
    resolution: {integrity: sha512-ejHwrQQYcm9xnTivShn2IDOlIzInN34AXskvq9QicvCtEzq1Vzclu/tKF8Jq1Cg8JG2GL6/EmjgsCT7lXepE3g==}
    engines: {node: '>=6.9.0'}

  '@babel/helper-module-transforms@7.29.7':
    resolution: {integrity: sha512-UPUVSyXbOh627KiCIGQSgwWzGeBKLkaJ9PJEdrngIwMSzxLR4jS4+f1f1jb7VzBbg8nFLaYotvVPFCTqdrmTAg==}
    engines: {node: '>=6.9.0'}
    peerDependencies:
      '@babel/core': ^7.0.0

  '@babel/helper-plugin-utils@7.29.7':
    resolution: {integrity: sha512-G7sHYigPY17oO5SYWnfD/0MTBwVR781S/JI643e/JhUYgVgWE/61SoW3NH9KWUKyKq5LVh3npif99Wkt6j86Jw==}
    engines: {node: '>=6.9.0'}

  '@babel/helper-string-parser@7.29.7':
    resolution: {integrity: sha512-Pb5ijPrZ89GDH8223L4UP8i6QApWxs04RbPQJTeWDV0/keR2E36MeKnyr6LYmUUvqRRI+Iv87SuF1W6ErINzYw==}
    engines: {node: '>=6.9.0'}

  '@babel/helper-validator-identifier@7.29.7':
    resolution: {integrity: sha512-qehxGkRj55h/ff8EMaJ+cYhyaKlHIxqYDn682wQD7RNp9UujOQsHog2uS0r2vzr4pW+sXf90NeeayjcNaX3fFg==}
    engines: {node: '>=6.9.0'}

  '@babel/helper-validator-option@7.29.7':
    resolution: {integrity: sha512-N9ZErrD+yW5geCDtBqnOoxmR8+tNKiGuxKlDpuJxfsqpa2dFcexaziGAE/qoHLiDDreVNMupxGmSoNlyvsA3gw==}
    engines: {node: '>=6.9.0'}

  '@babel/helpers@7.29.7':
    resolution: {integrity: sha512-1k2lAGRMfHTcwuNYcCNUmaUffmQv8KWMfh2iJUUeRlwlwH4FdNG7mfPI10NPfLHJFThE4Tyr4mv7kTNZOiPuBg==}
    engines: {node: '>=6.9.0'}

  '@babel/parser@7.29.7':
    resolution: {integrity: sha512-hnORnjP/1P/zFEndoeX+n+t1RwWRJiJpM/jO7FW32Kn9r5+sJB2JWOdYo4L6k78j15eCwY3Gm/7364B1EMwtNg==}
    engines: {node: '>=6.0.0'}
    hasBin: true

  '@babel/plugin-syntax-class-properties@7.12.13':
    resolution: {integrity: sha512-fm4idjKla0YahUNgFNLCB0qySdsoPiZP3iQE3rky0mBUtMZ23yDJ9SJdg6dXTSDnulOVqiF3Hgr9nbXvXTQZYA==}
    peerDependencies:
      '@babel/core': ^7.0.0-0
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

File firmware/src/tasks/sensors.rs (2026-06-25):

use core::fmt::Write;
use defmt::{Debug2Format, debug, info, unwrap};
use embassy_time::Timer;
use esp_hal::{
    Blocking,
    i2c::master::{Config, I2c},
    peripherals,
    time::Rate,
};
use heapless::String;
use veml7700::Veml7700;

use crate::{
    CALIBRATE_REF_CHANNEL, CLIENT_CONNECTED, MEASUREMENT_DATA_WATCH, MEASUREMENT_STATE,
    MeasurementData, MeasurementState, RGB_MULTIPLIERS_WATCH, SETTINGS_DATA_WATCH,
    helpers::{
        calibration::auto_calibrate_gray_reference,
        median_buffer::RunningMedianBuffer,
        v33::{
            apply_rgb_multipliers, apply_spectral_response_correction,
            spectral_correction_from_rgb, take_rgb_white_balance_calibration,
        },
        v77::{is_filament_inserted, take_baseline_reading},
        veml3328::Veml3328,
    },
    tasks::{leds::set_led_brightness, states::init_dev_info},
};

pub type VEML7700<'d> = Veml7700<I2c<'d, Blocking>>;
pub type VEML3328<'d> = Veml3328<I2c<'d, Blocking>>;

#[embassy_executor::task]
pub async fn sensor_task(
    _sda_v77: peripherals::GPIO6<'static>,
    _scl_v77: peripherals::GPIO5<'static>,
    _sda_v33: peripherals::GPIO8<'static>,
    _scl_v33: peripherals::GPIO10<'static>,
    _i2c_per: peripherals::I2C0<'static>,
) {
    let dev_state_sender = MEASUREMENT_STATE.sender();
    dev_state_sender.send(MeasurementState::Warmup);

    let mut v77 = get_v77();
    v77.enable().unwrap();
    Timer::after_millis(200).await;
    set_led_brightness(100);
    info!("LED at 100%");
    Timer::after_millis(150).await;
    let v77_baseline_bright = take_baseline_reading(&mut v77).await;
    set_led_brightness(25);
    info!("LED at 25%");
    Timer::after_millis(150).await;
    let v77_baseline_dark = take_baseline_reading(&mut v77).await;

    drop(v77);
    let mut rgb_white_balance: Option<(u16, u16, u16)> = None;
    let mut rgb_bufs: Option<(
        RunningMedianBuffer<100>,
        RunningMedianBuffer<100>,
        RunningMedianBuffer<100>,
    )> = None;

    let mut v33 = get_v33();
    let has_color = v33.enable().is_ok();
    init_dev_info(has_color).await;

    if has_color {
        Timer::after_millis(5).await;
        rgb_white_balance = Some(take_rgb_white_balance_calibration(&mut v33).await);
        rgb_bufs = Some((
            RunningMedianBuffer::new(),
            RunningMedianBuffer::new(),
            RunningMedianBuffer::new(),
        ));
    }

    let mut lux_buf: RunningMedianBuffer<100> = RunningMedianBuffer::new();

    let mut client_connected_sub = unwrap!(CLIENT_CONNECTED.receiver());
    let mut rgb_multi_sub = RGB_MULTIPLIERS_WATCH.anon_receiver();
    let mut settings_sub = SETTINGS_DATA_WATCH.anon_receiver();
    let mut calib_sub = unwrap!(CALIBRATE_REF_CHANNEL.subscriber());

    let mm_data_pub = MEASUREMENT_DATA_WATCH.sender();
    dev_state_sender.send(MeasurementState::Idle);

    loop {
        if !client_connected_sub.get().await {
            set_led_brightness(0);
            client_connected_sub.changed().await;
        }
        let saved_algorithm = settings_sub.try_get().expect("No Settings available").algo;

        let (is_filament_inserted, _) = {
            let mut v77 = get_v77();
            is_filament_inserted(&mut v77, v77_baseline_dark, saved_algorithm.threshold).await
        };

        if !is_filament_inserted {
            lux_buf.clear();
            if let Some((buf0, buf1, buf2)) = &mut rgb_bufs {
                buf0.clear();
                buf1.clear();
                buf2.clear();
            }
            dev_state_sender.send_if_modified(|v| {
                let changed = *v != Some(MeasurementState::Idle);
                *v = Some(MeasurementState::Idle);
                changed
            });
            mm_data_pub.send_if_modified(|v| {
                let changed = *v != Some(None);
                *v = Some(None);
                changed
            });

            continue;
        }

        // Filament detected
        info!("Filament detected");
        dev_state_sender.send_if_modified(|v| {
            let changed = *v != Some(MeasurementState::FilamentInserted);
            *v = Some(MeasurementState::FilamentInserted);
            changed
        });

        set_led_brightness(100);
        Timer::after_millis(300).await;

        let readings_per_call = 3;

        for i in 0..readings_per_call {
            // Longer delay to ensure fresh VEML7700 readings
            if i > 0 {
                Timer::after_millis(100).await; // Increased from 15ms to 60ms
            }

            {
                let mut v77 = get_v77();
                let lux_reading = v77.read_lux().unwrap_or(0.0);
                debug!("Raw lux: {}", lux_reading);
                lux_buf.push(lux_reading);
            }
            if has_color {
                let mut v33 = get_v33();
                if let (Ok(r), Ok(g), Ok(b), Ok(c)) = (
                    v33.read_red(),
                    v33.read_green(),
                    v33.read_blue(),
                    v33.read_clear(),
                ) {
                    debug!("RGB readings {}: R={}, G={}, B={}, C={}", i + 1, r, g, b, c);

                    let buffers = rgb_bufs.as_mut().unwrap();
                    buffers.0.push(r as f32);
                    buffers.1.push(g as f32);
                    buffers.2.push(b as f32);
                }
            }
        }
        let buffer_count = lux_buf.len();

        let final_median_lux = lux_buf.median().unwrap();

        if !has_color {
            let td_value = (final_median_lux / v77_baseline_bright) * 10.0;
            let adjusted_td_value = saved_algorithm.m * td_value + saved_algorithm.b;
            mm_data_pub.send(Some(MeasurementData {
                td: adjusted_td_value,
                buf_count: Some(buffer_count as u32),
                hex_color: None,
            }));
        }
        let rgb_multipliers = rgb_multi_sub
            .try_get()
            .expect("No RGB Multipliers available");
        let rgb_wb = rgb_white_balance.unwrap();

        if let Some(cmd) = calib_sub.try_next_message_pure() {
            info!("Calibration requested");

            let result = auto_calibrate_gray_reference(
                cmd,
                final_median_lux,
                rgb_bufs.as_mut().unwrap(),
                rgb_wb,
                rgb_multipliers,
            )
            .await;

            match result {
                Ok(cal) => {
                    RGB_MULTIPLIERS_WATCH.sender().send(cal);
                }
                Err(e) => {
                    info!("Calibration failed: {:?}", Debug2Format(&e));
                }
            }
        }
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

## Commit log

2024-07-06 Link to different ESP32-C3
2024-07-16 :sparkles: Create aio build for CI to upload with single file to esp32
2024-10-14 :sparkles: V3 with PCB
    [partitions.csv, td-free.csv, td-free.kicad_pcb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]
2024-10-26 Add V1.2 PCB without wrong condensator
    [td-free.kicad_pcb, td-free.kicad_sch]
2024-10-26 Optimize trace on PCB
    [td-free.kicad_pcb]
2024-12-20 :bug: Pin rust toolchain for github action
2025-03-09 :sparkles: First Prototype for improved PCB
    [freerouting.dsn, td-free.csv, td-free.kicad_pcb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]
2025-03-15 :sparkles: First test with new PCB
    [td-free.kicad_pcb, td-free.kicad_sch]
2025-03-28 :sparkles: PCB Progress
    [td-free.kicad_pcb, td-free.kicad_sch]
2025-04-12 :sparkles: New PCB working, software backwards compatible
    [td-free.kicad_pcb, td-free.kicad_sch]
2025-04-17 :bug: Adjust to also allow HF in Serial Connection
    [main.rs]
2025-04-27 :bug: Sending TD data to HueForge with only one digit precision
    [main.rs]
2025-05-05 Add serial barcode to PCB
    [td-free.kicad_pcb]
2025-06-07 Added median and outlier filtering to the code and slightly increased the sample count
2025-06-27 sensor ALMOST works. Bit banging allows the correct values, only need to do calibration and correct display
    [helpers.rs, main.rs]
2025-06-27 running median buffer, wifi retry and some color calibration
2025-06-27 Sensor initial tests, baseline rgb reading at 25%
2025-06-28 calibration is still not quite right
2025-06-28 calibration help
2025-06-28 custom calibration and TD adjustment still needs work
2025-06-28 calibration, slider changes, nvs key bug fix
    [helpers.rs, main.rs]
2025-07-06 reworked wifi a bit to keep the connection alive in the background. Work on color calibration and trying to always use 100% led during measuring to reduce measuring noise.
    [main.rs]
2025-07-06 removed the websocket connection. It broke frequently and the fallback polling method is simple and robust.
    [main.rs]
2025-07-06 calibration now finally works correctly. Still need to calculate the correct value for the automatic brightness adjustment. Also, we currently keep the led at 100% all the time, which helps in reduci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
    [main.rs]
2025-07-06 Forgot to set the new calibration TD.
2025-07-06 The color calibration and values now finally work correctly. Currently, there is still a small discrepancy under a td of 2.0 that gets bigger as we get near zero. I'll probably have to find a good va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
    [main.rs]
2025-07-12 wifi is now it's own thread. index.html has now a custom color picker. Calibration block is collapsable.
2025-07-12 readded hueforge connection. This currently does not work for me, but I would guess that this is a linux hueforge problem.
    [main.rs]
2025-07-13 Pin espflash and update CI toolchain
2025-07-14 Basic main optional rgb sensor
2025-07-14 Optional RGB sensor
2025-10-18 Improvements with Async and fixes with buffers not being passed around correctly
    [main.rs]
2025-12-26 Fix LED dimming down after measurement
2026-06-11 :sparkles: Progress
    [partitions.csv]
2026-06-12 Fix workflow uploading to correct bucket
2026-06-12 Call enable on sensor init
2026-06-13 Add more padding in time after led brightness change
2026-06-14 Add LED indication
2026-07-06 RGB LED Hardware
    [freerouting.dsn, led.kicad_pcb, main.kicad_pcb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]
2026-07-11 RGB LED basic sw
    [led.kicad_pcb, led.step, main.kicad_pcb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]
2026-10-19 New PCB Cleanup
